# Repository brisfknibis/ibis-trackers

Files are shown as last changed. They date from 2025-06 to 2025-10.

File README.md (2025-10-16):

| Add me | Vyro VR Discord | SlimeVR Discord |
| --- | --- | --- |
|  |  |  |

# 🪶 Ibis Trackers

DIY nRF52840-based, full-body tracking (FBT) trackers, built on [Smol Slimes](https://docs.slimevr.dev/smol-slimes/index.html). Originally created by [Lyall](https://github.com/LyallUlric/Stacked-SmolSlime).

---

## 🧠 How It Works

Unlike Wi-Fi SlimeVR trackers, **Smol Slimes (nRF trackers)** connect via a **USB receiver**, offering:
- ⚡ Low power consumption
- 🔋 ~30+ hrs battery life with 120 mAh battery
- 🖥️ PC connection required for the SlimeVR server

> [!NOTE]
> You must connect your receiver to a PC running the SlimeVR server.  
> Works with Standalone Quest VRChat via OSC bridge.  
> 👉 Read the [SlimeVR documentation](https://docs.slimevr.dev/) if you’re new to this.

---

## 🧰 Components

| Component | Notes | Link |
|---|---|---|
| ProMicro NRF52840 | Main MCU board | [AliExpress](https://www.aliexpress.com/item/1005007738886550.html) |
| 2-pin Tactile Button (2mm) | 2.5mm button requires lid mod | [AliExpress](https://www.aliexpress.com/item/1005001302607169.html) |
| 401230 3.7V 110 mAh LiPo Battery | Any similar-sized battery works | [AliExpress](https://www.aliexpress.com/item/1005006327425971.html) |
| SlimeVR ICM-45686 Mumo Module | LSM6DSR is a cheaper alternative | [SlimeVR Shop](https://shop.slimevr.dev/products/slimevr-mumo-breakout-module-v1-icm-45686-qmc6309) |
| Holyiot nRF52840+PA Receiver | Receiver board | [AliExpress](https://www.aliexpress.com/item/1005004673179004.html) |
| 30mm Ibis Tracker Straps | Any 30mm strap works | [VyroVR Store](https://vyrovr.com/product/ibis-tracker-straps/) |

> [!WARNING]
> Buy at least 20% extra MCUs and IMUs.  
> Example: building 8 trackers → buy 10 boards.  
> Trust me, you’ll break some.

---

## 🛠️ Assembly & Setup

- 📄 Follow the official Smol Slimes assembly guide: [docs.slimevr.dev/smol-slimes](https://docs.slimevr.dev/smol-slimes/index.html)  
- 🖱️ Flash firmware, solder components, and pair with your receiver.  
- ⚙️ Configure your setup in the [SlimeVR Server](https://docs.slimevr.dev/).

---

## 🙌 Credits

- 🧠 **[ManicQuinn](https://github.com/ManicQuinn/SlimeVR-Gremlin)** – inspiration and internal sizing  
- 🧱 **[Sorakage033](https://github.com/Sorakage033/SlimeVR-CheeseCake)** – case design inspiration  
- 🐶 **[Lexie](https://github.com/sctanf)** for their hard work on the firmware
- 🐺 **[Lyall](https://github.com/LyallUlric/Stacked-SmolSlime) for being the GOAT for Stacked Smol Slimes
- 🟣 Everyone in the community who tested, broke, fixed, and bought these trackers.
---

## 📜 License

<a href="https://creativecommons.org/licenses/by-nc-sa/4.0/">
  
  
  
  
</a>

Ibis Trackers © 2025 by [Bris Ibis](https://github.com/brisfknibis) is licensed under [CC BY-NC-SA 4.0](https://creativecommons.org/licenses/by-nc-sa/4.0/).

For **commercial licensing**, contact [vyrovr@gmail.com](mailto:vyrovr@gmail.com).

---

## 🐛 Contributing

PRs and improvements are welcome. If you break something, fix it. If you improve something, share it.  
If you solder upside-down… well, that’s on you.

---

✅ **Quick links:**  
- [Assembly Guide](https://docs.slimevr.dev/smol-slimes/index.html)  
- [SlimeVR Docs](https://docs.slimevr.dev/)  
- [Buy Straps](https://vyrovr.com/product/ibis-tracker-straps/)  
- [Report Issues](https://github.com/brisfknibis/ibis-trackers/issues)

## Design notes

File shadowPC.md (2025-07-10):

# 🕹️ Using Smol Slimes with Shadow PC

Smol Slimes use **nRF** chips instead of ESP. They don't use Wi-Fi — they rely on a dedicated **nRF USB Receiver** that must be plugged in and forwarded to your **Shadow PC**. To make this work remotely, you’ll use:

- 🛜 [**Tailscale**](https://tailscale.com) – for a secure private network between your local PC and Shadow
- 🔌 [**VirtualHere**](https://www.virtualhere.com/) – to forward USB devices over that network
- 🎮 [**SlimeVR**](https://docs.slimevr.dev/) – runs on Shadow and tracks your IbisTrackers once the receiver is active

## Requirements

- Smol Slimes + nRF USB Receiver (whatever came with your Smol Slimes, or which you made yourself)
- Shadow PC Account, with SteamVR (and games of your choice)
- Tailscale (installed on **both PCs**)  
- VirtualHere USB Server (on your **local PC**)  
- VirtualHere USB Client (on your **Shadow PC**)
- SlimeVR Server (installed on **Shadow PC**)

## ⚙️ Setup Guide

### 1. 🔌 Plug in the nRF Receiver

Connect your **nRF receiver** to a USB port on your **local PC**.

### 2. Install and Set Up Tailscale

- Download Tailscale: [https://tailscale.com/download](https://tailscale.com/download)
- Install it on **both your local and Shadow PCs**
- Log into the **same Tailscale account** on both devices
- On your **local PC**, open Tailscale and copy your **Tailscale IP address**  

> [!TIP]
> **Tip:** You can also get the IP from the [Tailscale admin panel](https://login.tailscale.com/admin/machines) if needed.

### 3. Launch VirtualHere USB Server on Local PC
- Download the USB Server: [https://www.virtualhere.com/usb_server_software](https://www.virtualhere.com/usb_server_software)
- Run the app — no install required
- It should auto-detect the connected USB receiver

> [!NOTE]
> You don’t need to configure anything in the USB server. Just keep it running in the background.

### 4. Run VirtualHere USB Client on Shadow PC

- Download the USB Client: [https://www.virtualhere.com/usb_client_software](https://www.virtualhere.com/usb_client_software)
- Open the app
- Right clicking "USB Hubs" -> Specify Hubs -> Add
- Paste in your **local PC’s Tailscale IP address**
- On the Shadow PC, you should now see a list of USB devices forwarded from your local PC

> [!IMPORTANT]
> If nothing shows up, make sure both machines are online and connected via Tailscale. Try restarting both VirtualHere apps.

### 5. Forward the nRF Receiver

- In VirtualHere on **Shadow PC**:
  - Find your receiver (often labeled `SlimeVR Receiver`, `SuperMini Receiver`, or similar)
  - Right-click → **Use this device**

> [!TIP]
> Once forwarded, the receiver will no longer be usable on your local PC — this is expected!

### 6. Launch SlimeVR on Shadow PC

- Open **SlimeVR Server** on your **Shadow PC**
- Your trackers should automatically appear and connect.

> [!NOTE]
> If trackers don’t appear, try restarting the SlimeVR server after forwarding the device

### 7. Follow the SlimeVR Setup Docs

Once your trackers connect:

📖 Follow the SlimeVR setup guide to calibrate, configure body proportions, and set up bindings:  
👉 [https://docs.slimevr.dev/](https://docs.slimevr.dev/)

> [!WARNING]
> Do **everything** on your **Shadow PC** — running anything locally (like SteamVR or SlimeVR) will break tracking.

---

## 💡 Tips & Troubleshooting

> ✅ **Free Version Works!**  
> VirtualHere is **free for one device**, which is perfect for forwarding your single nRF receiver.

> 💻 **Run Everything on Shadow:**  
> SteamVR, VRChat, SlimeVR — all of it should be opened **only on Shadow PC**, never on your local machine.

> 🔄 **Trackers not showing?**  
> Try the following:
> - Restart SlimeVR
> - Re-forward the USB device
> - Check for nRF receiver driver issues on Shadow PC

> 🔐 **Tailscale not connecting?**  
> - Make sure both devices show as "Connected" in the Tailscale dashboard
> - Use `tailscale ip` in Command Prompt to double-check IPs

---

## ✅ You're Good to Go!

You’re now running your SlimeVR nRF trackers entirely on **Shadow PC**, with the nRF receiver being tunneled through **Tailscale** using **VirtualHere**.  
SlimeVR sees the trackers like they’re plugged in directly — no WiFi, no desync, and no unusual configuration required.

Enjoy your full-body tracking!

<3 Bris Ibis

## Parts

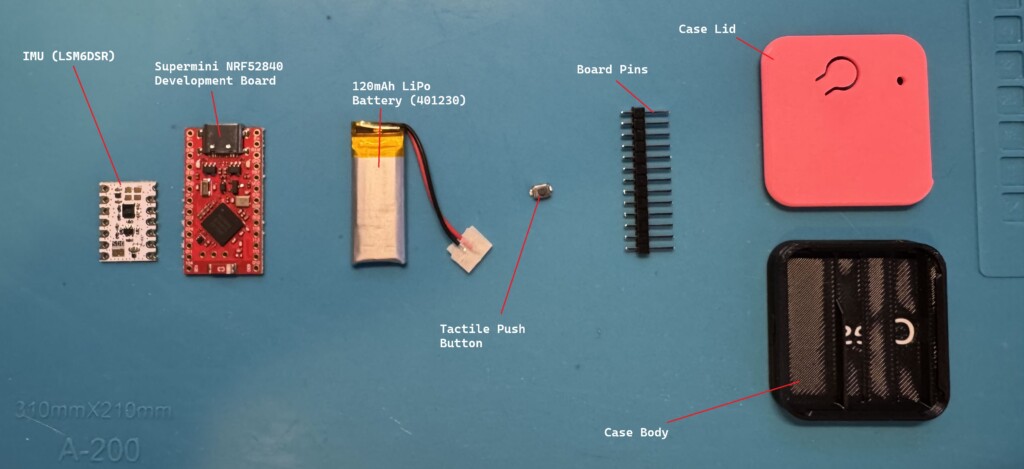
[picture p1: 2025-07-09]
Images/process/raw-components-1-1024x469.jpg

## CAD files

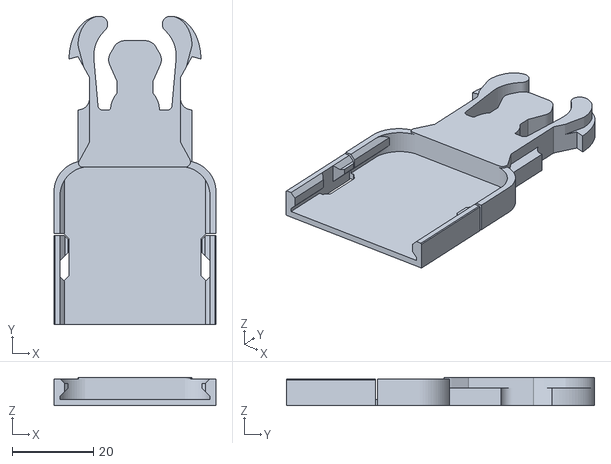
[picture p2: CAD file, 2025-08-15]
3D Print Models/Chrysalis GoPro Chest Mount.stl
39.8 x 75.8 x 7.00

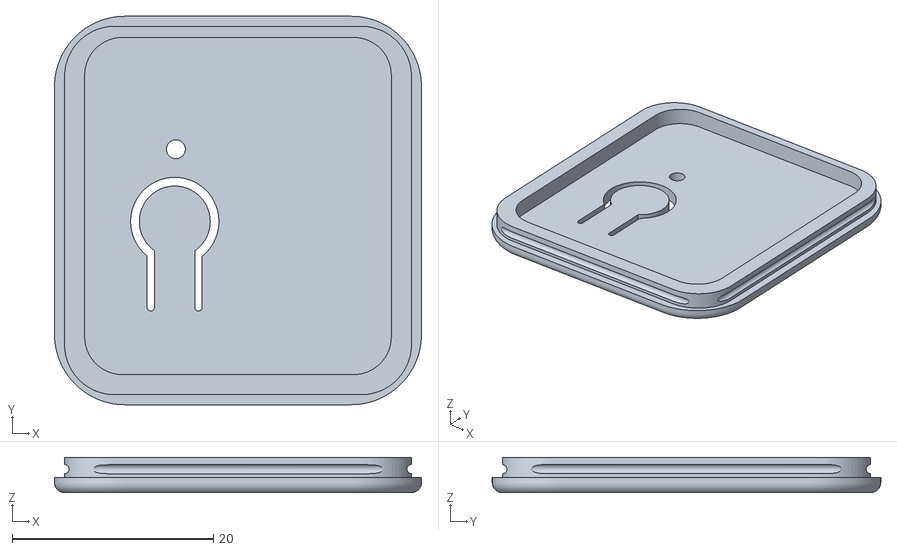
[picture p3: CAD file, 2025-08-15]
3D Print Models/Chrysalis Lid.stl
36.5 x 38.7 x 3.50

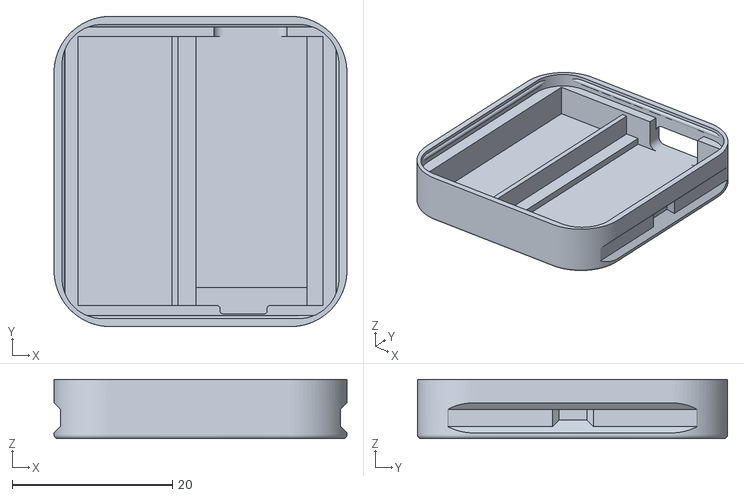
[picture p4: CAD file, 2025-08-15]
3D Print Models/Chrysalis Body.stl
36.5 x 38.7 x 7.40

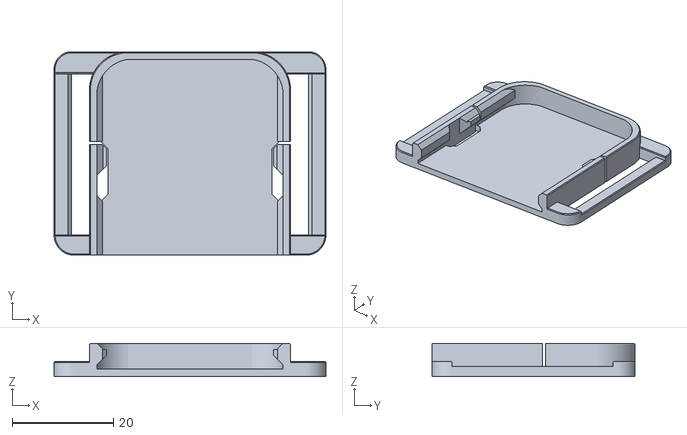
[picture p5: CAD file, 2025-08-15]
3D Print Models/Chrysialis Tray.stl
53.8 x 40.3 x 6.56

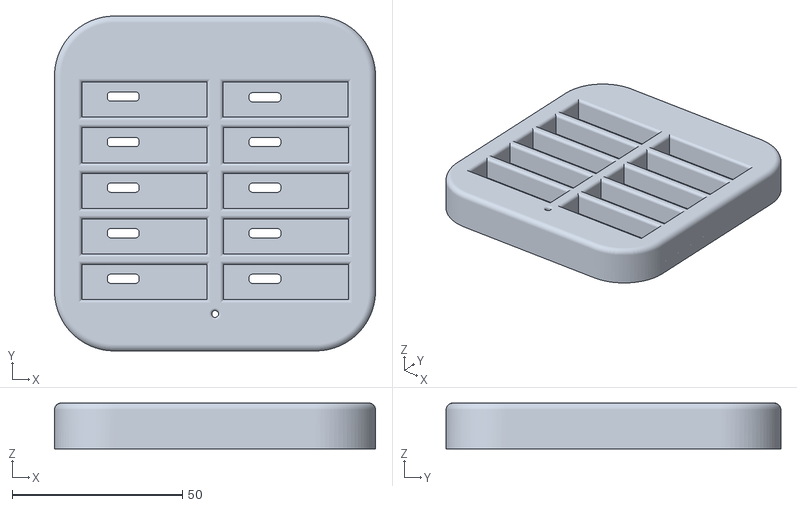
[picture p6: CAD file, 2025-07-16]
3D Print Models/Dock Top.stl
94.4 x 98.5 x 13.5

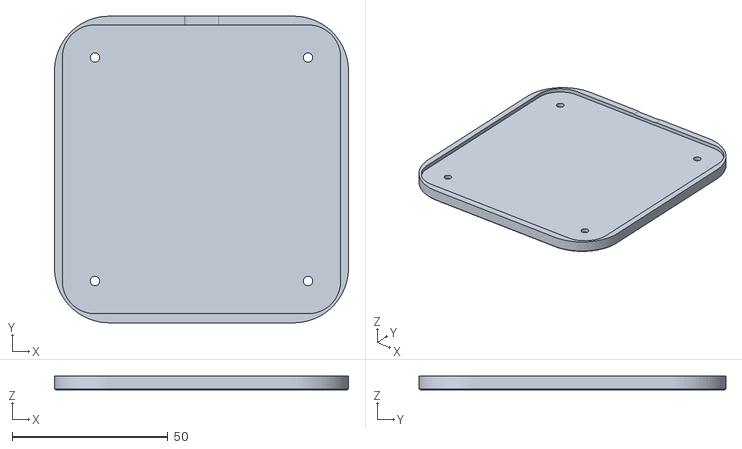
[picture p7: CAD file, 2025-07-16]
3D Print Models/Dock Base.stl
94.4 x 98.5 x 4.51

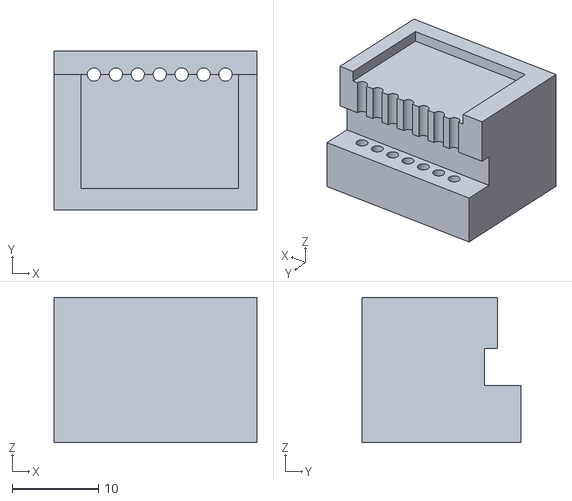
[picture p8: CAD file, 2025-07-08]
3D Print Models/Solder Cube.stl
23.5 x 18.4 x 16.8

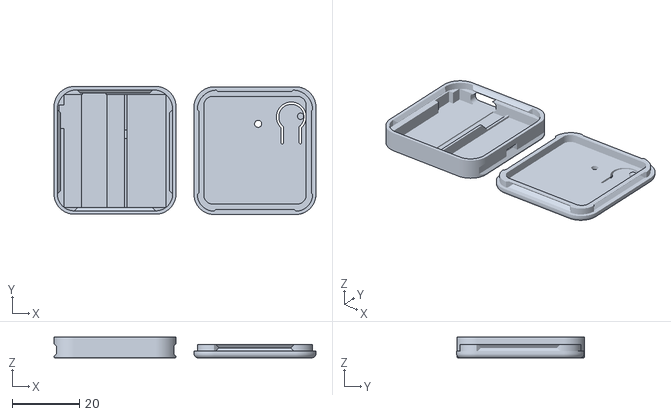
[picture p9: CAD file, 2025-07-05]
3D Print Models/Reversed Ibis Tracker Case.stl
78.1 x 38.2 x 6.20

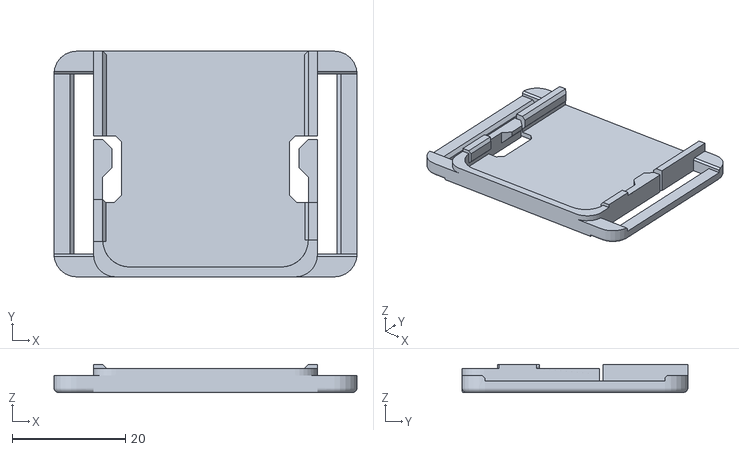
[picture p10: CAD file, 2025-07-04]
3D Print Models/Tray.stl
53.5 x 39.9 x 4.94

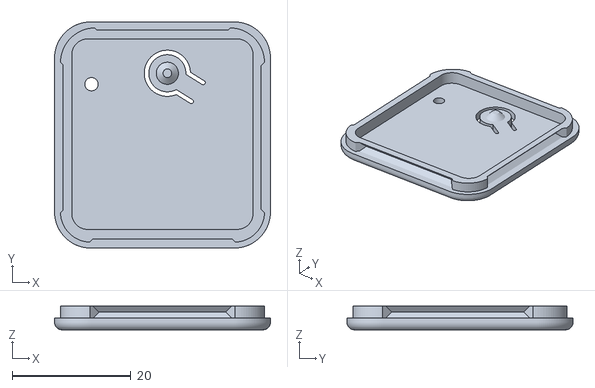
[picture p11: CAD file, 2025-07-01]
3D Print Models/Lid.stl
36.4 x 38.1 x 4.00

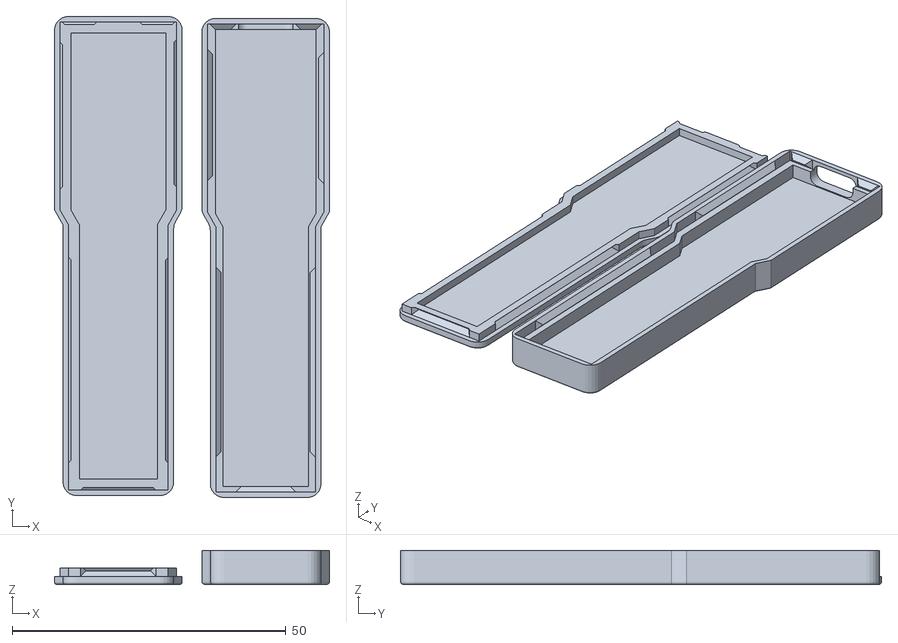
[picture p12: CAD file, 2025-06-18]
3D Print Models/Receiver.stl
50.3 x 87.9 x 6.24

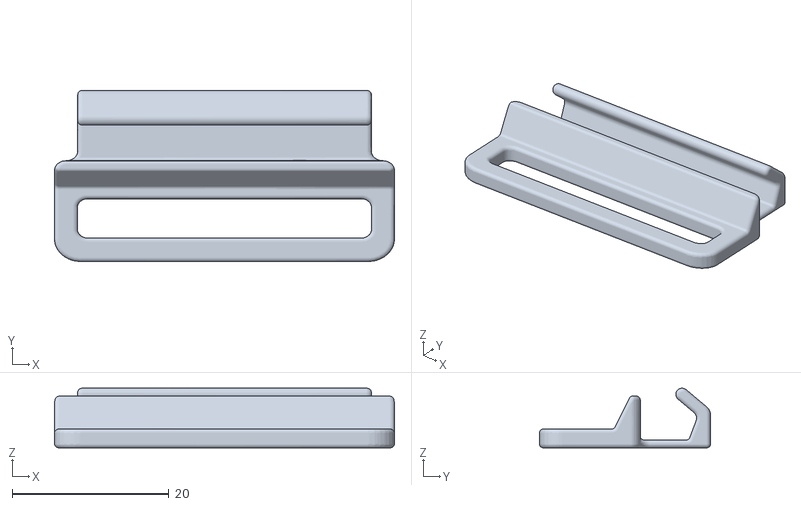
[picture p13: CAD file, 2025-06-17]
3D Print Models/38mm Hook.stl
43.3 x 21.8 x 7.61

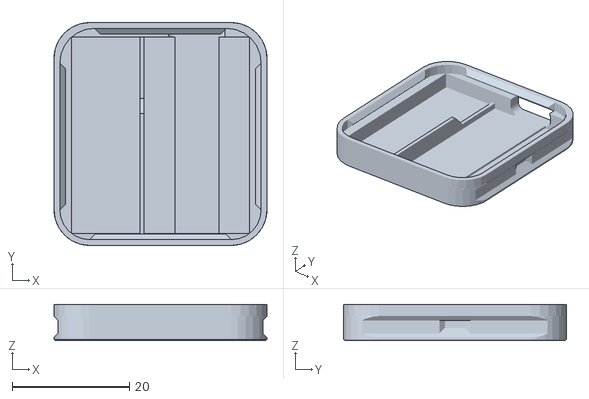
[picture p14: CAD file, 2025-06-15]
3D Print Models/Body.stl
36.4 x 38.1 x 6.20

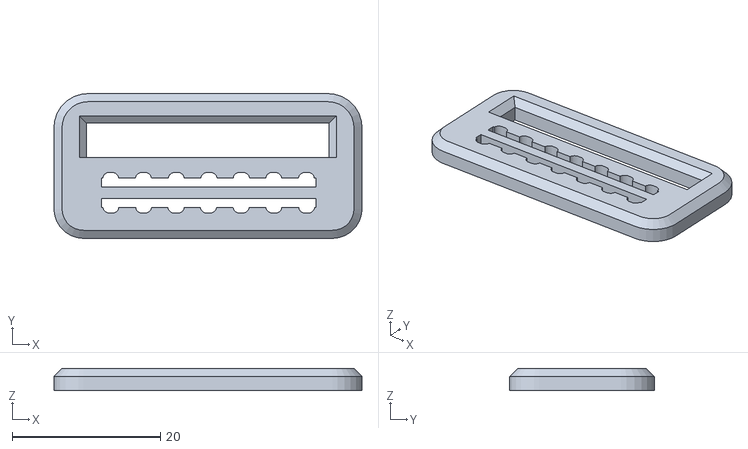
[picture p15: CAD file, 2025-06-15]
3D Print Models/30mm Grippy Eyelet.stl
41.6 x 19.5 x 3.01

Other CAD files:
3D Print Models/30mm Grippy Hook.stl
3D Print Models/38mm Grippy Eyelet.stl
3D Print Models/38mm Grippy Hook.stl
3D Print Models/30mm Hook.stl
3D Print Models/30mm Grippy Dovetail.stl
3D Print Models/GoPro Chest Mount.stl
3D Print Models/Tray v4.1.stl

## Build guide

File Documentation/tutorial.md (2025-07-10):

# How to make an Ibis Tracker (Stacked Smol Slimes: SlimeVR Compatible nRF Trackers)

> [!NOTE]
> Ibis trackers are SlimeVR Compatible full body tracking devices. They are "Smol Slimes", which means they use nRF instead of WiFi to connect to your PC. nRF is similar to Bluetooth, but with lower latency. To learn more, please visit the SlimeVR Documentation on Smol Slimes.

Ibis Trackers are completely open source, which means you can build your own if you have the time. They are identical to the product we sell. This guide will show you the process we take for each tracker.

## Parts Required

To make your trackers, you’ll need access to a 3D printer. You can also buy the 3D printed parts from us. You’ll also need:

- [ ] Stanley Knife (or something very sharp)
- [ ] Wire Cutters
- [ ] Wire Strippers
- [ ] Kapton Tape
- [ ] Fine tip soldering iron specifically for electronics (best if it has temperature control)
- [ ] Solder Flux
- [ ] Other tools that may make the process easier

### Tracker Components

Each tracker is made up of only a few components:

- [ ] IMU Module (ICM-45686 or LSM6DSR)
- [ ] SuperMini (ProMicro) nRF52840 or Seeed Studio equivalent board
- [ ] 120mAh LiPo Battery
- [ ] Small, tactile push button
- [ ] Board pins (should have come with your SuperMini)
- [ ] Wire for the antenna mod

## Component Preparation

To ensure each component fits correctly and works, there are a few steps we need to take before we assemble each tracker.

### IMU

The IMU will most likely come in rows of 5, and will have some little defects we want to shave off. Before then, if you still have them connected, you’ll need to add some Kapton tape to the back of them. This prevents solder from seeping through onto the SuperMini board later.

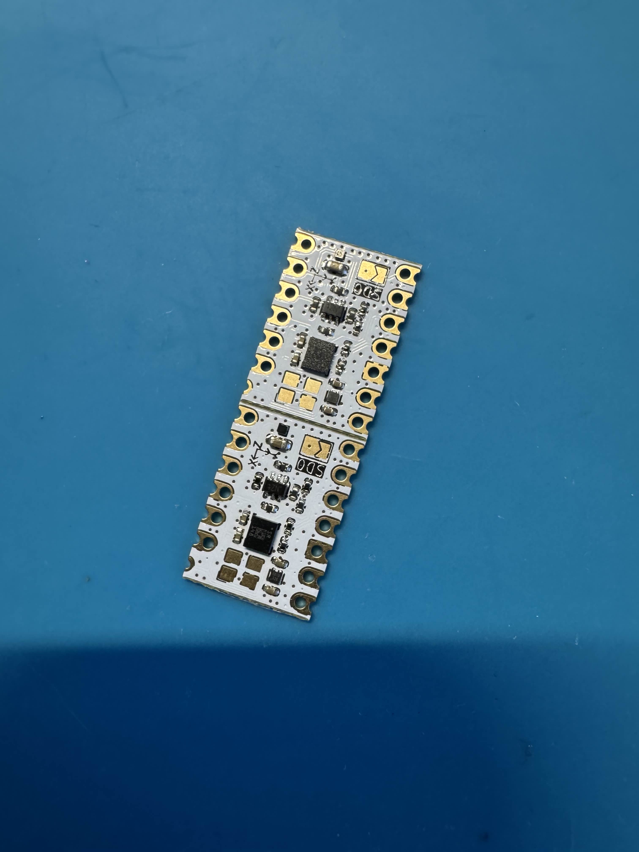
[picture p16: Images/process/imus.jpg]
LSM6DSR IMU modules joined still from factory.


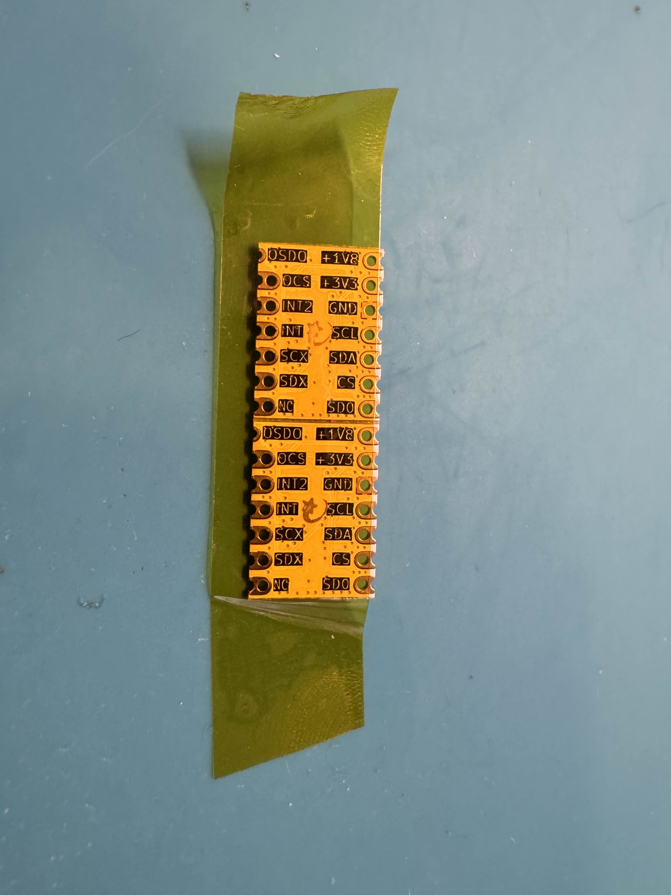
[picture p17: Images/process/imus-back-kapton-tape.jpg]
Add Kapton tape to the back of the IMUs, aligning the tape so the pins can still make contact with the side of the module.


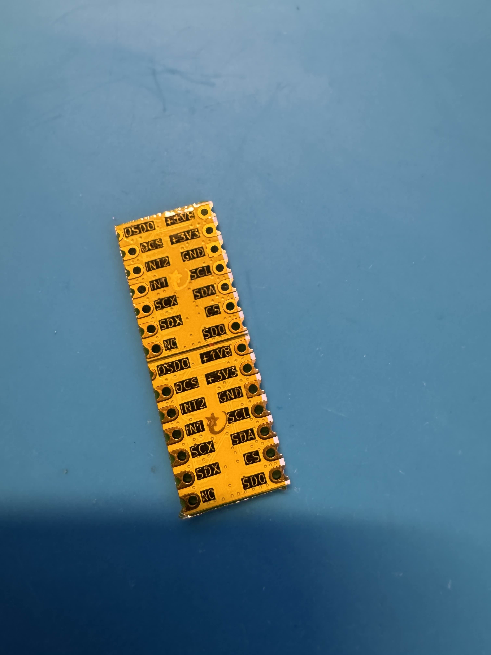
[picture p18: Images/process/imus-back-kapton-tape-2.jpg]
Cut the excess tape off.


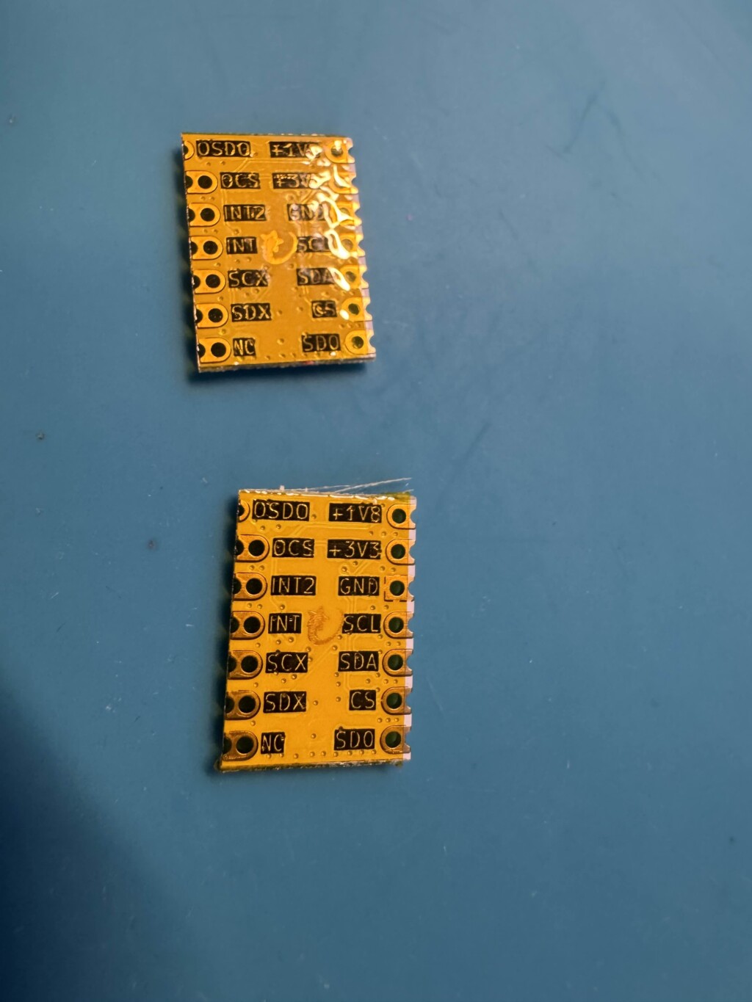
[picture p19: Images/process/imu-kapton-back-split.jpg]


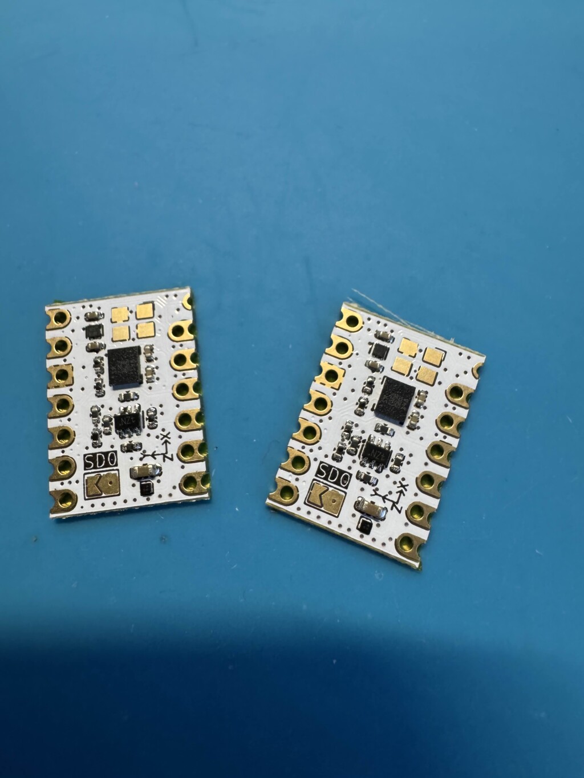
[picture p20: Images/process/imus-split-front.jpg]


Once you’ve separated and taped your IMU’s, you’ll want to shave off the excess from the top and bottom. This isn’t a required step, but helps clean them up a bit.

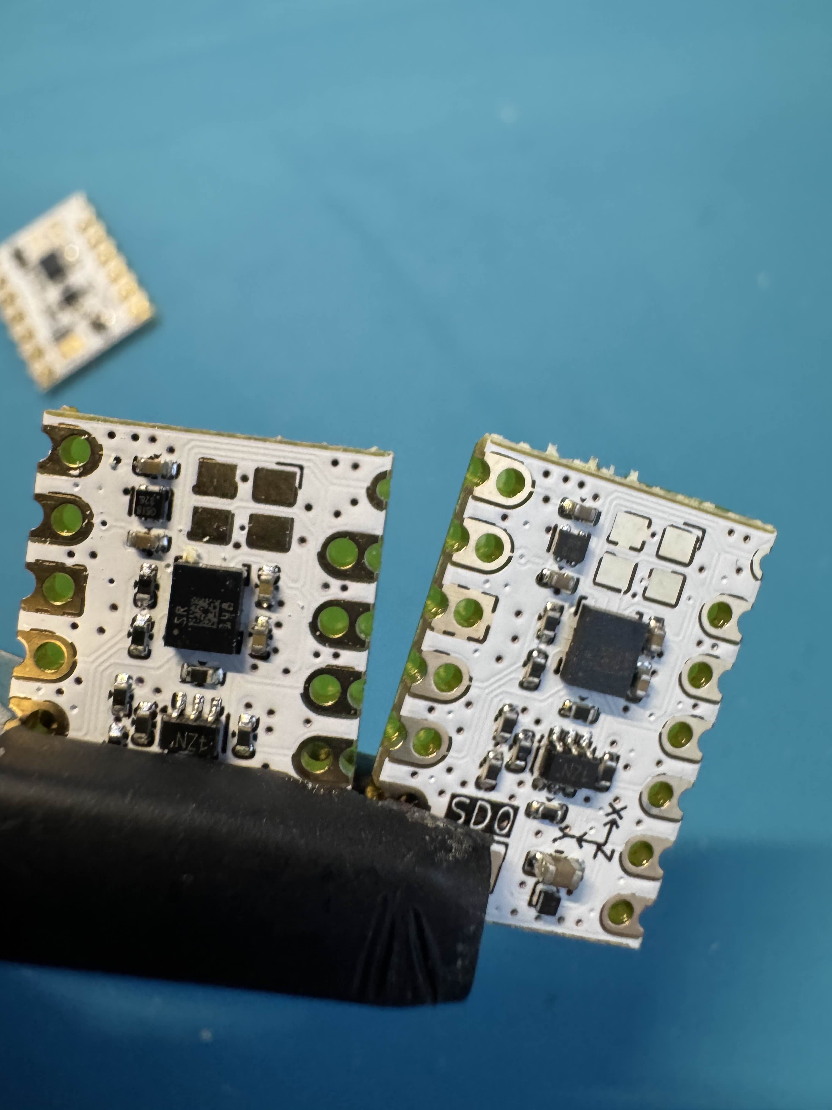
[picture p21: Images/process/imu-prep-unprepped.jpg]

<sub>Left: Shaved/cleaned up IMU vs. unshaved IMU on the right</sub>

#### Pre-Soldering The IMU

This step is as far as I can tell, unique to our process. I designed a “Soldering Cube” to help make this process less likely to destroy part of the SuperMini.

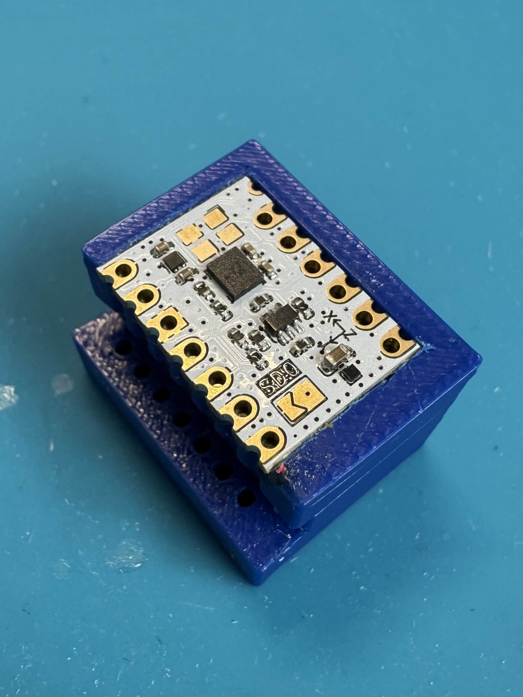
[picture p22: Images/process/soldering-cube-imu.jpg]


(You can get a Soldering Cube here.)[https://github.com/brisfknibis/ibis-trackers/blob/main/3D%20Print%20Models/Solder%20Cube.stl]

Take your pins, and split them in half. You’ll need a row of six:

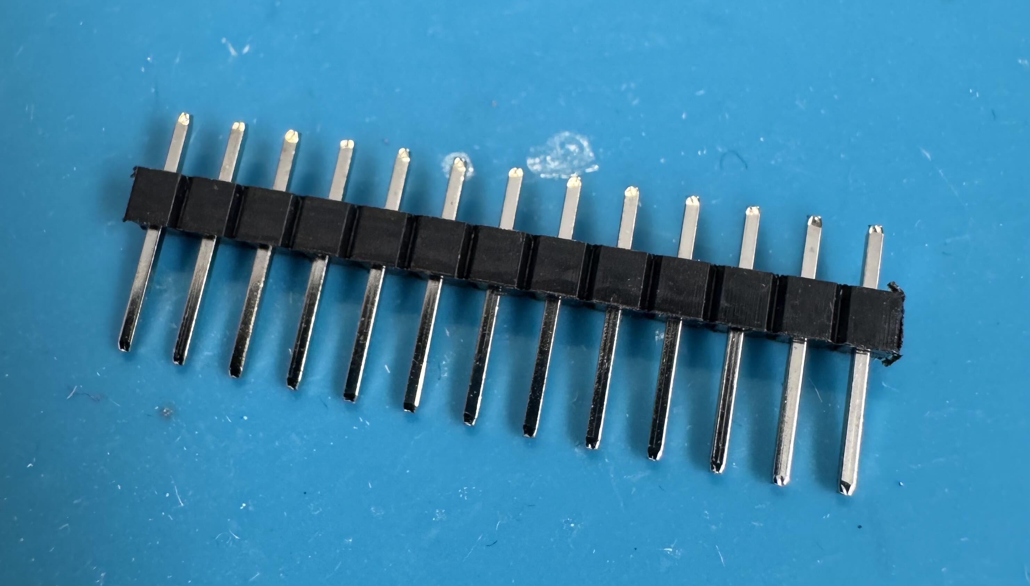
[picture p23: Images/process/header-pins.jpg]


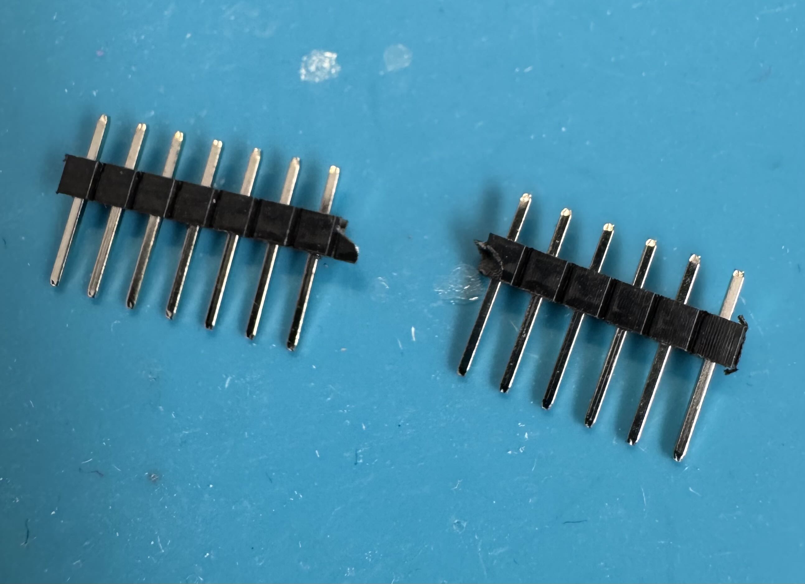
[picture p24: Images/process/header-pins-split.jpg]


Push the plastic on the 6 pins down towards the bottom. I use a breadboard to push the pins down easily. I also do this on my soldering mat, so they don’t go ALL the way to the bottom. about 1mm at the end is right.

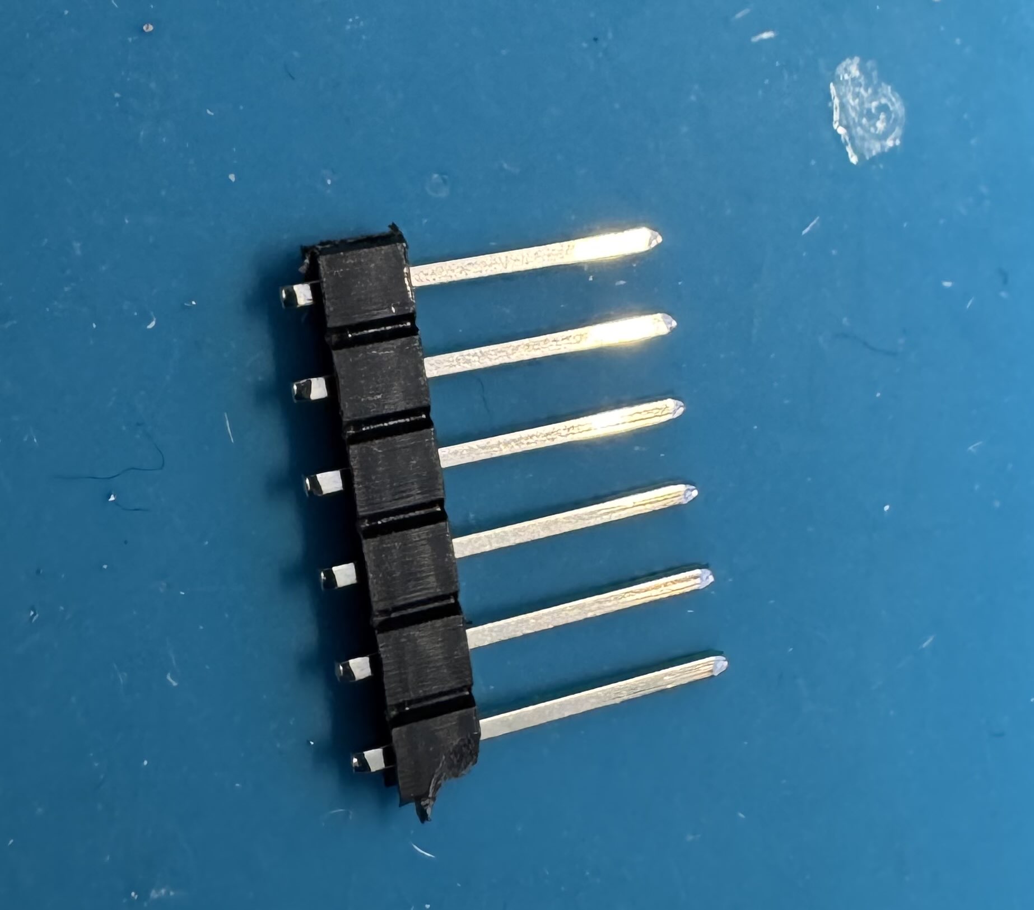
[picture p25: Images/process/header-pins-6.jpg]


Place the pins in the soldering cube with the IMU.

Tile the cube on the side so we can more easily solder the pins.

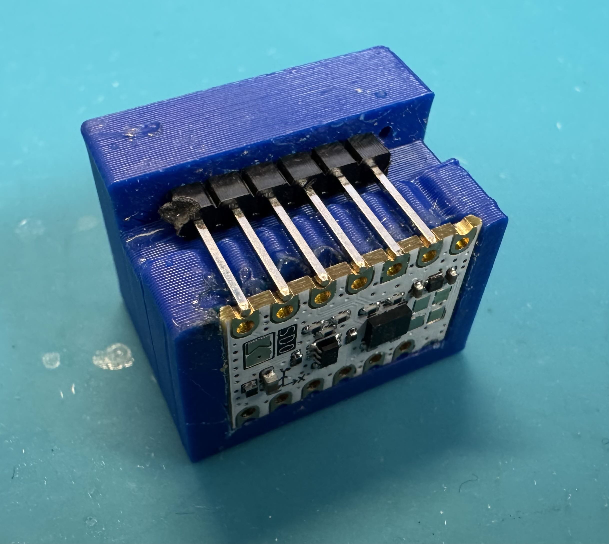
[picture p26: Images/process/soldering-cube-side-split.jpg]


I prefer to solder the left, then the right most pins, then the inner ones. Just a little bit of solder first, then if you want, you can strengthen the connections with a bit more solder.

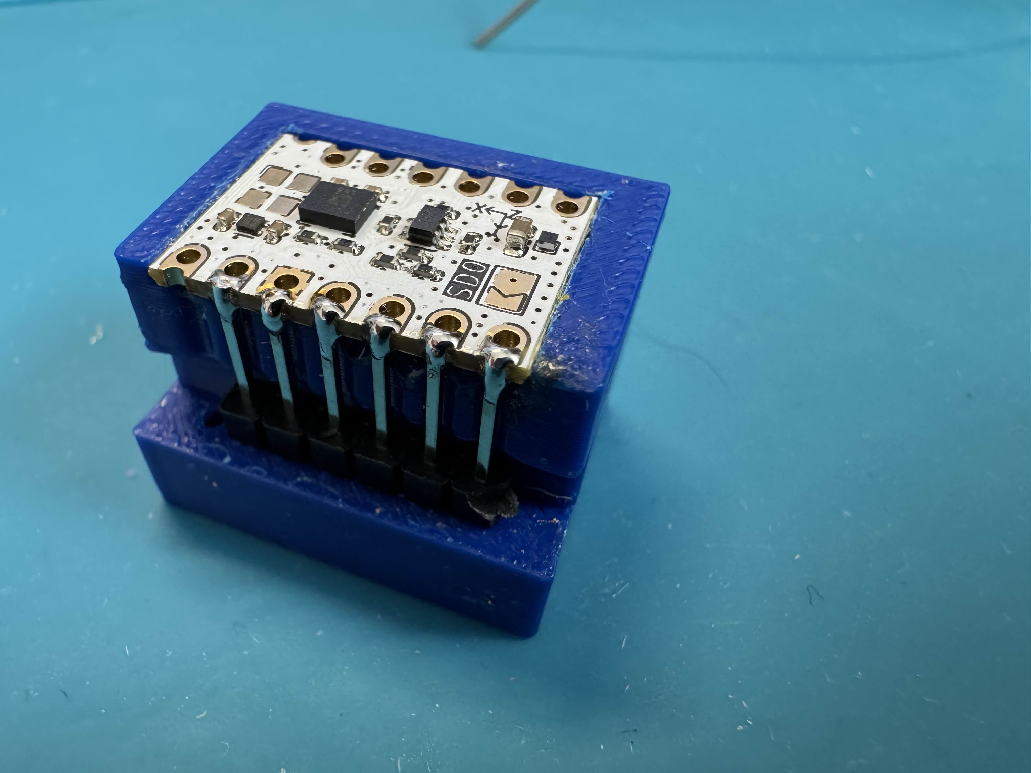
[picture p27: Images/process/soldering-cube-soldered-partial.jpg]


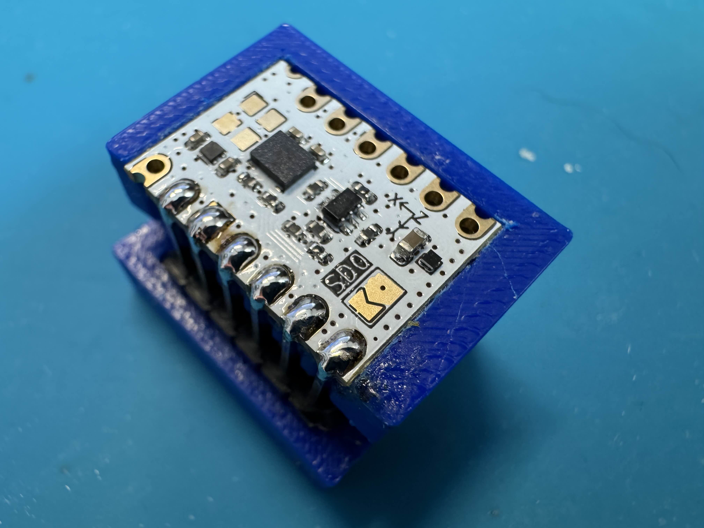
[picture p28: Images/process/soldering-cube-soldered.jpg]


Once you’re happy with your joints, I recommend cleaning it with a bit of Isopropyl alcohol or PCB cleaner to remove any flux from the soldering process.

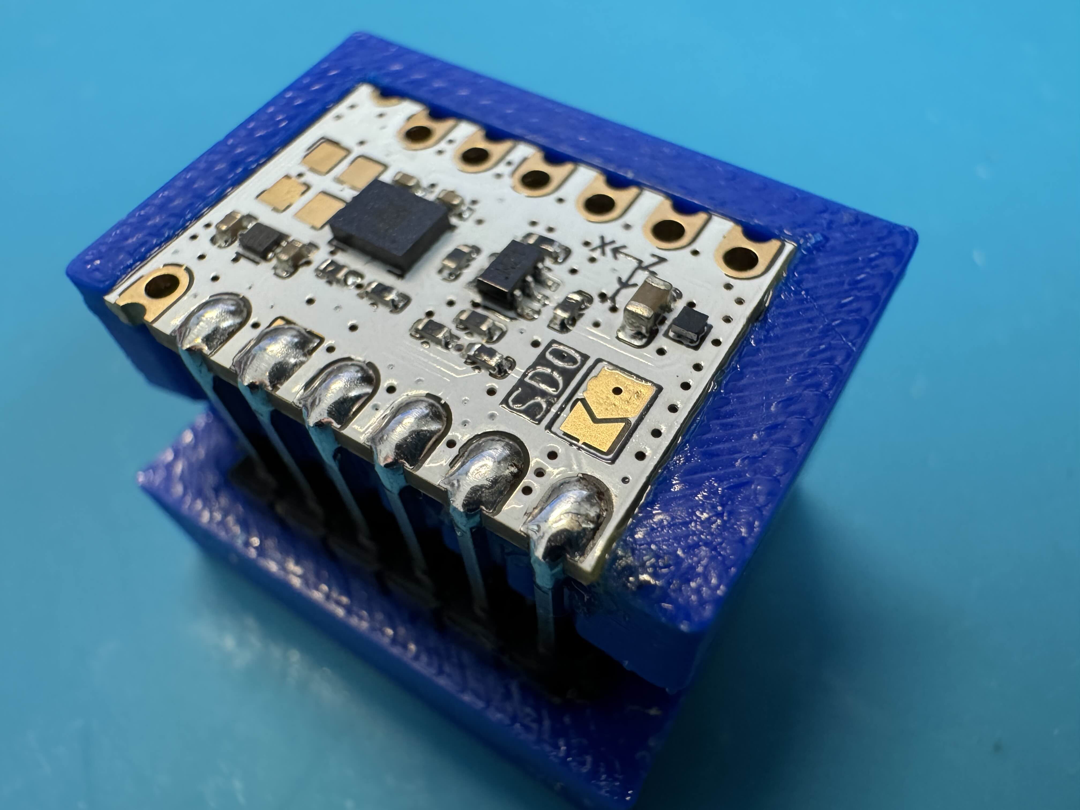
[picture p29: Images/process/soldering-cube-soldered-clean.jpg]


Remove the IMU from the soldering cube, and snip the pins as close to the plastic as possible. You can attempt to just slide the plastic off, but this risks pulling the pins off the IMU.

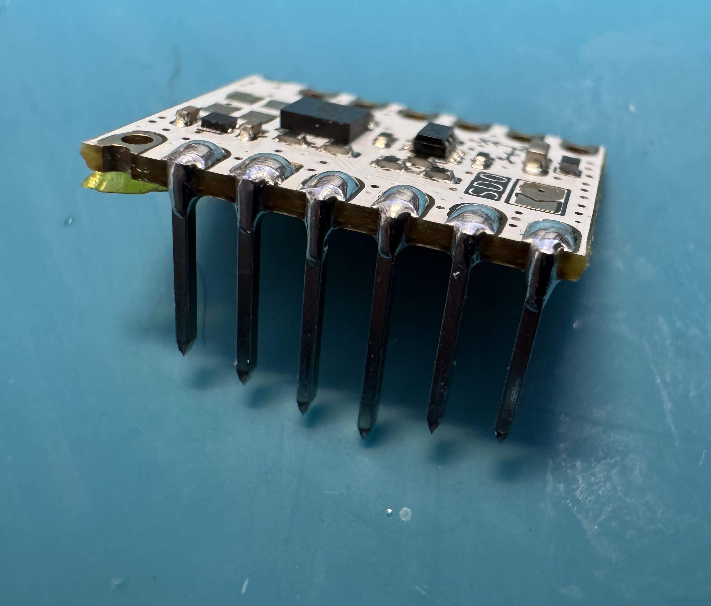
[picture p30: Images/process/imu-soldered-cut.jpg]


Now onto the SuperMini!

### SuperMini nRF52840

For the SuperMini development board, there are 3 steps to prepare this one. It’s also your main tracker board, so most steps will focus on this device.

#### Preparing the board

As with the IMU, you’ll want to shave off the excess from the sides of the unit. This is a requirement, otherwise it will not fit inside the case.

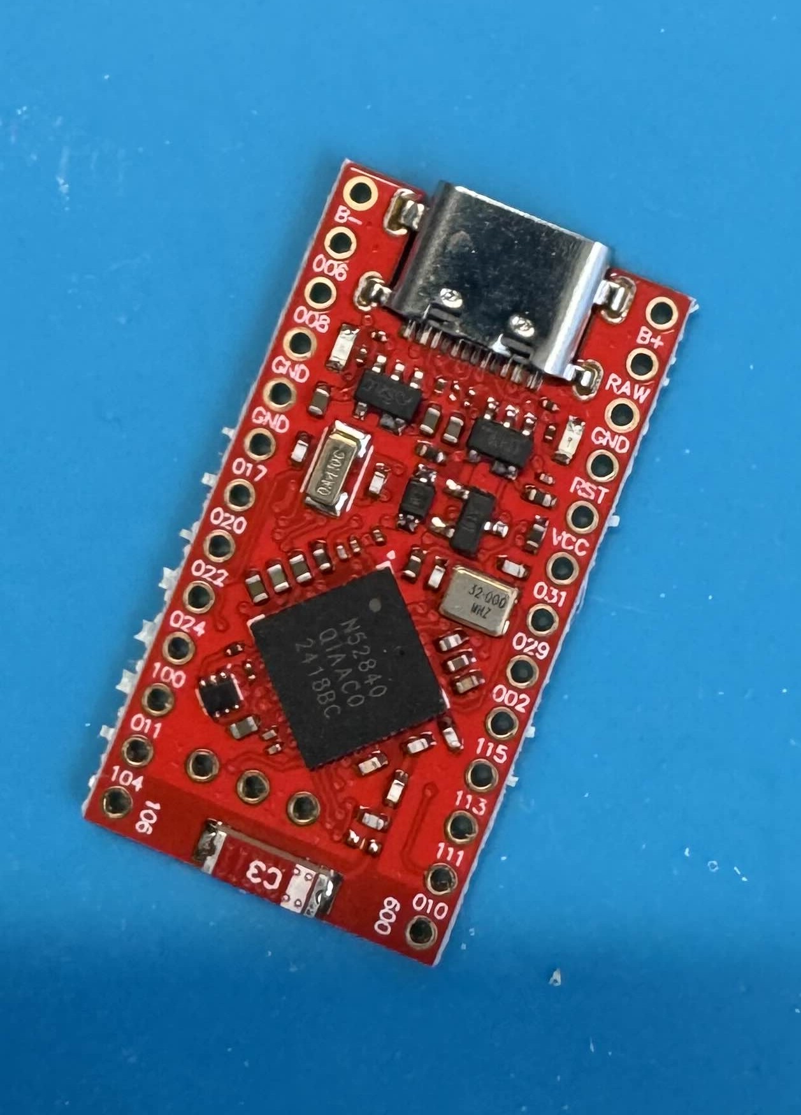
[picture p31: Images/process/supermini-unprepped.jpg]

<sub>SuperMini Module with edges that need to be cleaned up.</sub>

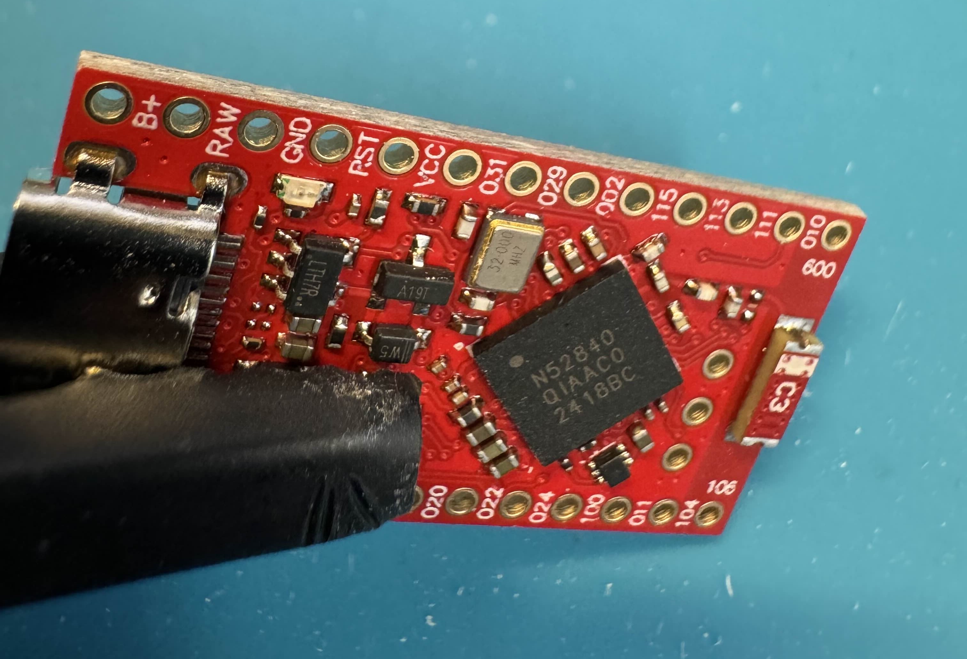
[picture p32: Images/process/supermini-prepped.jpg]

<sub>SuperMini nRF52840 with cleaned up edges. I used a Stanley knife for this one.</sub>

#### Flashing the Firmware

Before we start soldering, it’s best to ensure that the SuperMini actually works. Connect it via USB to your PC, and open the Serial Terminal in nRF Connect for Desktop app. The first sign of a good board is that it should be blinking like the following:

(video of SuperMini idle)

Next, we need to short the RST button to the GND pin. Alternatively, you can act as ground and use something metal to short the RST pin like this:

(video of SuperMini DFU)

Once you’ve shorted the pin by tapping it 2 times (sometimes it takes 2-5 times) the red light will fade/flash solid. Then, you can copy the .UF2 bootloader file to update the device BEFORE we flash it with the tracker firmware.

Download the Bootloader firmware here.

To copy the firmware, simply copy and paste the bootloader file above to the “NiceNano” drive that appears in your computer. It should look like a USB Drive.

(Download the Bootloader firmware here.)[https://github.com/SlimeVR/Adafruit_nRF52_Bootloader/releases/download/0.9.2-SlimeVR.7/update-slimenrf_promicro_bootloader-0.9.2-SlimeVR.7_nosd.uf2]

To copy the firmware, simply copy and paste the bootloader file above to the “NiceNano” drive that appears in your computer. It should look like a USB Drive.

(nicenano-pc.jpg)

Your SuperMini will reset, and the drive will disappear. If you see it in the Terminal, it most likely worked. It may appear like a “Feather” device in your Serial Terminal.

(serial-terminal-feather.png)
[Updated Bootloader. Non-updated will look the same, or may have a different name.]

(serial-terminal-nicenano.png)
[A SuperMini in “DFU” mode, ready to be flashed with firmware]

Next, we need to flash the SlimeVR Tracker Firmware.

(Download the latest SlimeVR Tracker Firmware here)[https://github.com/Shine-Bright-Meow/SlimeNRF-Firmware-CI/releases/download/latest/SlimeNRF_Tracker_NoSleep_SPI_StackedSmol.uf2]

Short the RST pin again and copy the above file. Once done, the tracker should appear in the terminal like this:

(serial-terminal-slimenrf-tracker.png)

You can now connect to the tracker, and check everything so far is working:

(serial-terminal-connect-to-port.png)

(serial-terminal-info.png)

Looks like we’re working!

In the text input above, type “info”:

(serial-terminal-info-screen.png)
(Info screen for a tracker with no IMU attached.)

Great! That’s enough for us to continue to the next stage.

#### Pre-Soldering the Board 

There are a few points I prefer to pre-solder to make life easier for us later. Fill the following pins with solder. We’re adding solder to the battery connectors, button contacts, and the antenna for the antenna mod (right side only!)

(supermini-solder-points)
[Solder these points]

(SuperMini soldered points)
[Pre-Soldered SuperMini. 006, GND, B+, GND (right side) and the right side of the C3 antenna.]

Lastly, we want to pre-solder the button.

(supermini-button-soldered)

#### Assembly

To assemble the IMU to the SuperMini, we need to connect the 6 pins from the left side of the IMU to the 6 pins on the left side of the SuperMini starting from the THIRD PIN, 011.

(imu position on supermini)

Flip the SuperMini upside down with the IMU inserted into the correct pins, and snip off the excess pin length:

(back side supermini pins up)
[SuperMini with IMU pins that need to be snipped]

(back side pins snipped)
[Pins have now been snipped!]

Solder the pins from the back, and clean off any excess Flux from your solder job.

(supermini back soldered)
[SuperMini with pins soldered from the back for the IMU.]

(supermini soldered top)

Usually, you should solder the pins so they are creating a good contact. This one is okay because the pins are connected correctly from the back. Notice on most of these, they don’t appear to have a good soldered connection on the top. I find this to be okay, and even optimal, because too much solder can short the connections with one another.

#### Check the Connection

Before we do the final assembly steps, you’ll want to connect the tracker to your PC and check to see if the IMU is detected. If it’s detected, you should see info logs about motion and status switching. Type “info” into the text box, and you should see something like this:

(serial terminal info with imu)
[IMU will show as the model if it is detected.]

If your terminal is being spammed with yellow warnings, type “Reboot” and this should hopefully clear it. If no IMU is detected, you may need to go back and check your soldering connections and try again.

In our case, everything is working as expected, so we can solder the last pin, “002”, on the right hand side. Note that the pin labels are underneath the pins, not above them, so you want to solder a pin in the hole between “002” and “029”.

(circled supermini)

(supermini with row of pins right side)

Using the remaining pins, place them in the holes. Solder pin “002”.

(supermini right side soldered pin plastic still there)

You should be able to then pull out the rest of the pins from the plastic, leaving just the one remaining.

(supermini soldered right side staning pin solo)

NOTE: If you are using ICM-45686 modules, you will ALSO need to solder the lowermost pin on the IMU to pin 111 on the SuperMini. Leaving you with two soldered pins on the right side.

Fold the pin down so it’s touching the IMU, then snip the top.

(supermini right side bent pin)
[Bent the pin towards the IMU]

(snipped pin)
[Snipped pin]

Solder the connection, and be sure to clean off any flux.

(soldered right side)

#### Connecting the Wire Mod

SuperMinis have horrendous signal strength as they are. To get the most out of them, the best option is to cut a 31mm wire (3.1cm) and connect it to the RIGHT side of the C3 antenna.

(4 pics of wire mod)

#### Connecting The Battery

A little trick I use, is I use the Antenna Mod to hold the SuperMini upright, so I can solder the battery Negative terminal from the back side and push it in.

(Battery Connection pics)

Once you have soldered the negative terminal, you can then do the final step and connect the positive terminal to B+.

### You just built a Stacked Smol Slime Tracker!

(Completed Tracker)

Put it in a case, and enjoy!

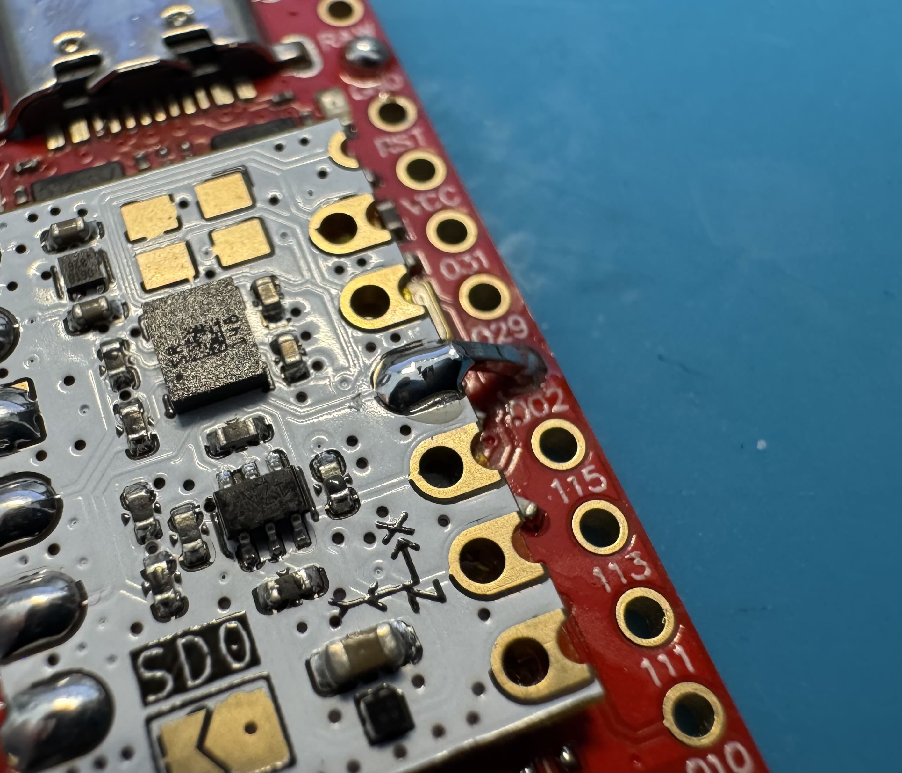
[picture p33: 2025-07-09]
Images/process/supermini-pin-bent-soldered-imu-complete.jpg

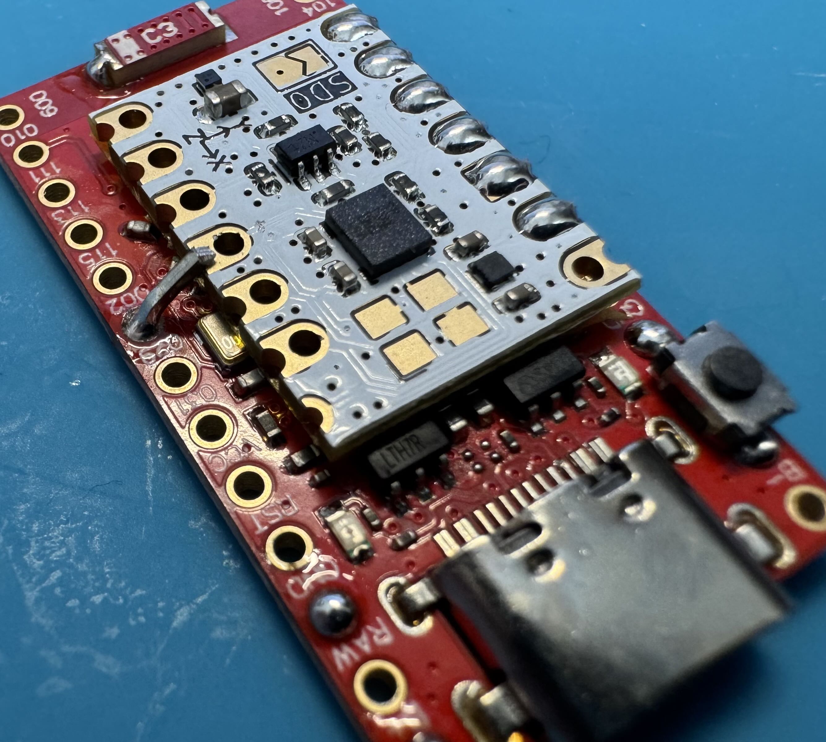
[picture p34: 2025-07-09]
Images/process/supermini-imu-pin-bent-soldered-.jpg

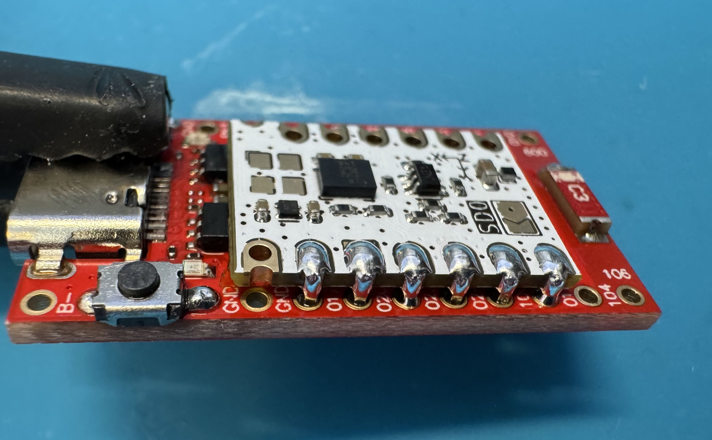
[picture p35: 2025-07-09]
Images/process/supermini-pins-soldered-front.jpg

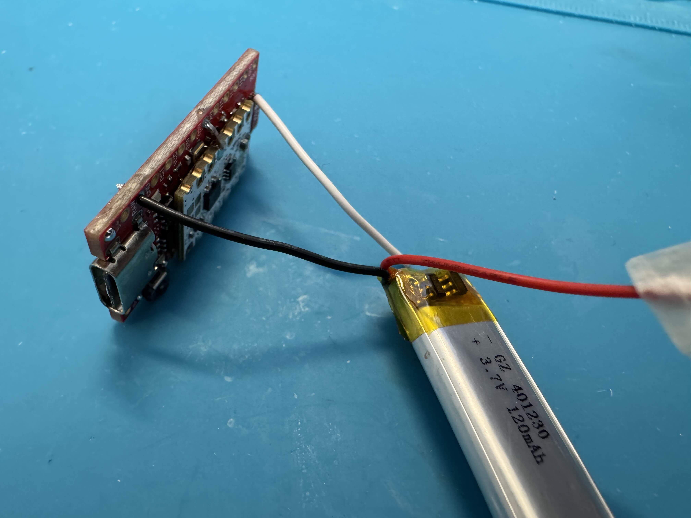
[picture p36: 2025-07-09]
Images/process/battery-ground-wire-soldered.jpg

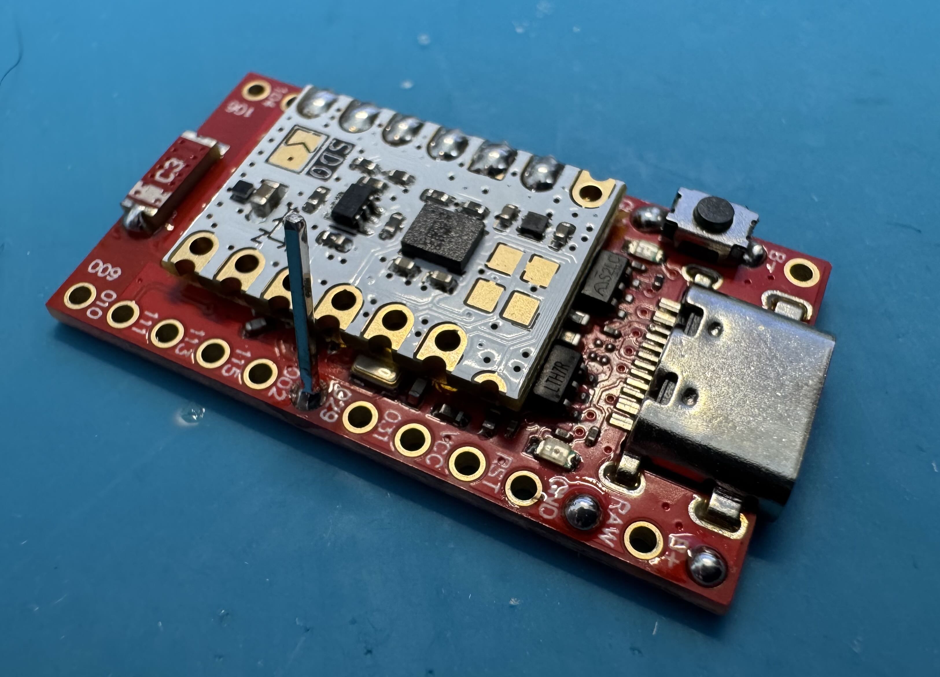
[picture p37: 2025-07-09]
Images/process/supermini-pin-soldered.jpg

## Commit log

2025-03-08 Added STL files
    [chest-mount-40mm-dovetail-eyelet.stl, chest-mount-40mm-dovetail-latch.stl, chest-mount-front-main.stl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]
2025-03-17 Updated 3D Files
    [30mmDovetailGrippy.stl, 30mmGrippyEyelet.stl, 38mm Hook Clip.stl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]
2025-03-26 Updated Print Files
    [Body.stl, Lid.stl, Transporting Tray.stl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]
2025-03-26 updated lid
    [Lid.stl]
2025-03-30 Added Different tray types
    [Body V4.stl, Lid V4.stl, Slide Tray.stl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]
2025-03-30 Fixed slider position on body and tray
    [Body V4.stl, Body v4.1.stp, Lid V4.stl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]
2025-03-30 Updated GoPor Mount
    [GoProChestMountAdapter2.stl, gopro chest mount clip 1.1.stl]
2025-03-30 Removed incorrect files
    [Body v4.1.stl, Body v4.1.stp, Slide Tray v4.1.stp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]
2025-04-01 removed old content
    [Body v4.1.stl, Body.stl, GoPro Chest Mount 4.1.stl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]
2025-04-02 Added NiceNano Case
    [10 Tracker set 1 of 2.3mf, 10 Tracker set 2 of 2.3mf]
2025-04-19 Added Firmware Flasher
    [10 Tracker set 1 of 2.3mf, 10 Tracker set 2 of 2.3mf, NiceNanoReceiverBody.stl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]
2025-05-02 Updates to 3D Print Files
    - Removed curved base on tracker body: easier to print
    - Added Dock V1.0
    - Removed hook with new, custom version with wider eyelet for Ibis Tracker Straps (remodeled instead of stolen without attribution)
    - Updated lid with thicker dome to allow easier button action, removed nipple
    [BrisCake 4.1 Flat base.stl, BrisDock Base v1.0.stl, BrisDock Top V1.1a.stl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]
2025-05-21 Update to include dock
    [30mmDovetailGrippy.stl, 30mmGrippyEyelet.stl, 38mm Hook Clip.stl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]
2025-06-07 Updated and renamed Ibis Tracker
    [BrisCake 4.1B.stl, BrisDock v5.1.stl, Ibis Tracker Body 1.0.stl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]
2025-06-15 Updated 3D Print Models
    [30mm Grippy Dovetail.stl, 30mm Grippy Eyelet.stl, 30mm Grippy Hook.stl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]
2025-06-17 Shrank hook a bit
    [38mm Hook.stl]
2025-06-18 Updated Dock and receiver
    [Dock Top.stl, Receiver.stl]
2025-07-01 Updated lid and dock
    [Dock Top.stl, Lid.stl]
2025-07-04 Tray Update to be more snug
    [Tray.stl]
2025-07-05 Added reversed case STL
    [Reversed Ibis Tracker Case.stl]
2025-07-05 Updated dock to fit M2 8mm Screws
    [Dock Base.stl, Dock Top.stl]
2025-07-08 Added Soldering Cube.
    [Solder Cube.stl]
2025-07-16 Updated dock to suit M2 screws and heat insert
    [Dock Base.stl, Dock Top.stl]
2025-08-15 removed firmware added chrysalis 3d models
    [Chrysalis Body.stl, Chrysalis Lid.stl, Chrysialis Tray.stl]
2025-08-15 updated design
    [Chrysalis Body.stl, Chrysalis GoPro Chest Mount.stl, Chrysalis Lid.stl]
2025-10-16 Update battery life information in README
